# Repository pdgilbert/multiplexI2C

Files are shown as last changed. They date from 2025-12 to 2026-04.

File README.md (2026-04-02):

# multiplexI2C
Eight 4-position screw connectors on multiplexed on I2C with PCA9548A. 
This allows connecting 8 I2C sensors such as AHT10 (on module boards) using 
low voltage 4-wire cable.

##  Status: Working Prototype.

## Summary

Kicad project WIP.

PCB design to connect multiple (up to 8) I2C sensors (eg. AHT20) to a I2C multiplexer
connecting to an MCU. Sensor connectors are  4-pin KF128-2.54-4P generic screw terminals.
Many types of I2C sensors are inexpensive and easily available on module boards, 
but 4-wire cable will typically need to be attached. 

The pcb board has a LoRa radio on a SPI bus which transmits measurement results.
There is also a I2C header for an optional OLED display, intended mainly for debugging.

Related software is in repository https://github.com/pdgilbert/SensorProject_th8.

As of December 2025, this repository has three important branches. (Branch `main` is not 
an important branch but rather a somewhat stable version of the most active
development, which is on the `dev` branch. Both may be removed or reorganized 
in the future.)
 
Branch `blackpill-socket` has two 20-pin sockets arranged for a commonly available 
blackpill module. It has an RFM95 LoRa radio on spi, an I2C pinsocket arrange to plug in 
an SSD module for display, and 8 4-pin terminals multiplexed to connect I2C devices.
The pinsocket arrangement can also be used for jumper-wiring MCUs on other development
boards. Further work on this branch will be limited.
 
Branch `f411-RFM95W-module` has a footprint for a module with an MCU and LoRa radio.
(See repository MCU-LoRa for module details.)
It has a socket for I2C arranged to plug in an SSD module for display, 
and 8 4-pin terminals multiplexed to connect I2C devices. 
As of November 2025 this branch is almost ready to manufacture a prototype.
 
Branch `f411-RFM95W` has an STM32F411 MCU and RFM95W LoRa radio on the board (no module).
It has a socket for I2C arrange to plug in an SSD module for display, 
and 8 4-pin terminals multiplexed to connect I2C devices. 
As of December 2025 this branch is almost ready to manufacture a prototype.

See history further below for regarding status and testing of each branch.

Graphics below will be different on different branches, reflecting the differences above.
The `.png` files below are produced from kicad  in the `3D Viewer`  
with `File > Export Current View as PNG`.
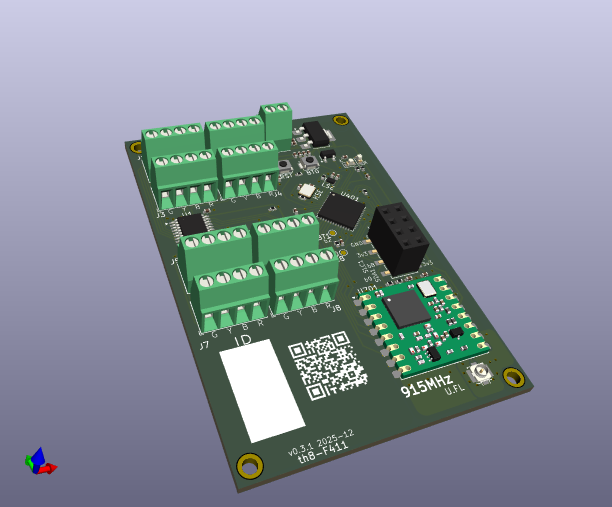
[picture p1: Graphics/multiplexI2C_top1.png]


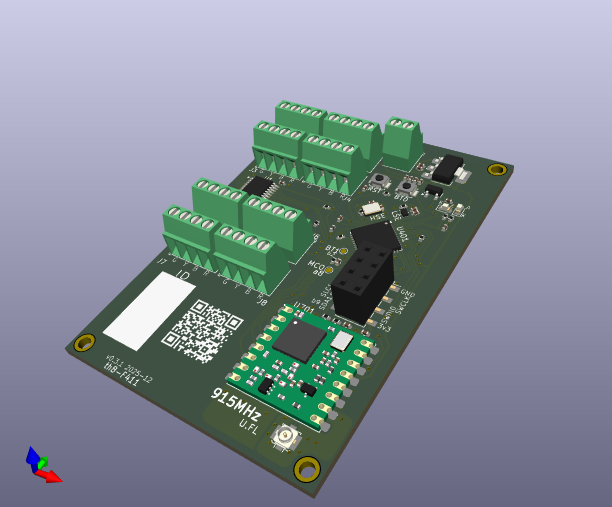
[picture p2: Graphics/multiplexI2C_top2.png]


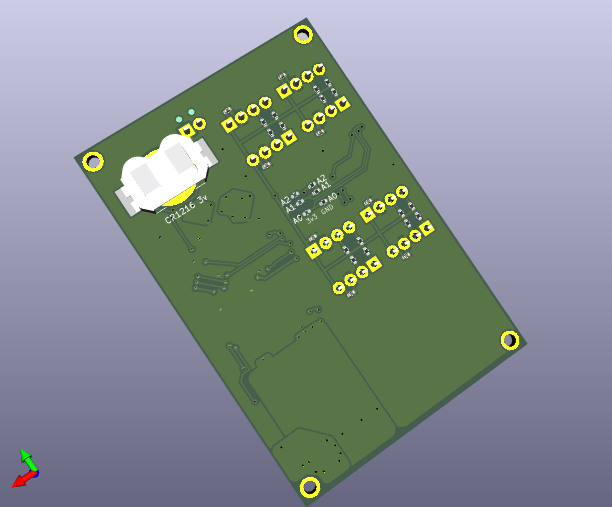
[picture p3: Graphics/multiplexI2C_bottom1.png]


( hints from https://docs.github.com/en/repositories/working-with-files/using-files/working-with-non-code-files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 )

3D  `.wrl` file opens with Meshlab. Good, full colour. 
The file needs to be load into a viewer (e.g.
https://3dviewer.net/#model=https://github.com/pdgilbert/multiplexI2C/f411-RFM95W/Graphics/multiplexI2C.wrl )
or downloaded and viewed with your own viewer. 
To download go to the file in the Graphics/ directory and click on the file.
Github will try to render this, but fails because it is too large.
Then click on the download raw file icon at the top right. 
The file is produced from kicad  with `File > Export ... >  VRML...`
.wrl file
https://3dviewer.net/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

3D  `.step` file can be loaded by Freecad. 
It can be load into a viewer (e.g. 
https://3dviewer.net/#model=https://github.com/pdgilbert/multiplexI2C/f411-RFM95W/Graphics/multiplexI2C.step)
or downloaded as above for `.wrl`.
The file is produced from kicad  with `File > Export ... >  STEP...`
.step file

3D  `.stl` file can be  rendered by Github, Meshlab and Freecad. So far only mono-colour is working. 
It can be load into a viewer (e.g. 
https://3dviewer.net/#model=https://github.com/pdgilbert/multiplexI2C/f411-RFM95W/Graphics/multiplexI2C.stl)
To render by Meshlab or Freecad requires downloading as above for `.wrl`.
The file is best produced by exporting a `.wrl` or `.step` file from kicad and
importing that to Meshlab or Freecad, and then exporting an `.stl` file.
The file can also be produced from kicad  with `File > Export ... >  STEP.../STEP...` but
the result has bad artifacts. The .wrl version is much better than the .stl version.
.stl file

3D  `.ast` file (ASCII stl) is rendered by Github, according to above link, but files  
larger than 10 MB are too big for GitHub to display. 
The `multiplexI2C.ast` is almost 20MB so this format cannot be used by Github.
It is not rendered by Meshlab.
.ast file

## History
 
 - `th8-F411` version `0.3.1 2025-12` (branch `f411-RFM95W`) has stm32f411 MCU chip and HopeRF RFM95W.
    This version is switched to ssd on I2C1 and sensors on I2C2, so it is consistent with SensorProject_t16.
    The software has a flag to indicate previous old versions.

 - `th8-F411` version `0.3.1M 2025-12` (branch `f411-RFM95W-module`) has not been manufactured/tested.

 - Version `0.1.1 2025-01` (branch `blackpill-socket`) has pull up resistor added but 
   has not been manufactured/tested. This version has ssd on I2C2 and sensors on I2C1.

 - Version `0.1.0 2024-09` (branch `blackpill-socket`) needs manual addition of a pull up 
   resistor to nss of the RFM95W radio module, MCU pin A4. 
   With this modification it works with `blackpill` `stm32f401` or `stm32f411` inserted,
   using AHT10 and AHT20 sensors. With jumper wiring it has also been used to test a WeAct 
   Studio STM32474G474 board.  This version has ssd on I2C2 and sensors on I2C1.
   See notes re testing in the software repository.

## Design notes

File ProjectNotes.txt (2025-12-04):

grep "/////////////// " ProjectNotes.txt   # for section index

////////////////////////////////////////////////////////////////////////////////
///////////////     General Notes
////////////////////////////////////////////////////////////////////////////////

(See also file `README.md`.)

The 8   4-wire screw down connectors provide gnd, 3.3v, and multiplex I2c (SCL and SDA). 

The PCB board is 48.26mm by 71.12mm, which fits (tightly) in a standard NA electric outlet hole. 
This allows for a standard outlet faceplate cover. The board needs to be supplied by low voltage (5v).
An outlet box is not a good option because of the number of sensor wires, but a low voltage single gang 
wall plate with no back, as often used for audio or TV cable, is a good option.

The mounting hole centers are 43.5mm apart in x direction and 66.4 mm in y direction.
On versions with the MCU-LoRa module one mounting hole is moved from the corner. 
It is 20.10mm  in the x direction from the adjacent hole.

In addition to the 8 multiplex I2c connectors and the LoRa module, the board has 
  - 4 pins on an 8 pin header to connect a ST-link programming dongle.
  - 4 pins on an 8 pin header to connect ssd display on I2C1.
  - a red led indicating when it is powered up.
  - a blue led on pin PC13 which can be programmed to turn on and off.
  - a 25 MHz crystal for the high speed external (HSE) oscillator. (still untested)
  - a 32.768 kHz crystal for the low speed external (LSE) oscillator. (still untested)
  - a coin cell battery holder to supply the real time clock (RTC). (still untested)
  
The HSE, LSE, and RTC are not used by current software but are on the board for future possibilities.

- AHT10 sensor module reference  https://www.electroschematics.com/temperature-sensor/

////////////////////////////////////////////////////////////////////////////////
///////////////            To Do
////////////////////////////////////////////////////////////////////////////////

- consider screwless terminal connector, eg KEFA  KF141V_4P 
  or  KF208VB-2.5/2.54  Spring type terminal block,
  (https://www.kefaelectronic.com/KF208VB-2-5-2-54-Spring-type-terminal-block-pd563040758.html)
  or Würth Elektronik	 691403900004B
  or https://abra-electronics.com/interconnects/terminals-blocks-barrier/spring-terminals/2427p-screwless-terminal-block-4-pin-0.1-pitch-top-entry-2-pack.html
  or  WAGO 2086-1104-700-000_997-605 but a bit smaller would be better,
  and SMT would be nice. Consider possibly multileveel 45 degree?
  or https://www.kefaelectronic.com/KFM736H4-Spring-type-terminal-block-pd555948668.html
     https://www.lcsc.com/category/432.html
     https://www.lcsc.com/product-detail/C2974939.html

-spice

////////////////////////////////////////////////////////////////////////////////
///////////////     BOM / Parts / reference
////////////////////////////////////////////////////////////////////////////////
     
========fabrication files ==========

Necessary files  https://www.pcbway.com/smt_ordering_guide.html

Generate BOM_auto.csv  and edit to BOM.csv

Generate 11 .grb files in ./outputs  

Generate  2 .drl files in ./outputs

[indicates  hole counts   plated pads: 127  non-plated:2  through vias:16  micro vias: 0  buried vias:0 ]

Generate centroid position file   > Fabrication Ouputs  > Component Placement (.csv not .pos)
[indicates componet count 56 ]
check  J**1 and J**2 and DNP R0 are removed or edit them from the file.

then  zip multiplexI2C-gerbers.zip  *.gbr *.drl

======= submit and get Quote ========

Following  (The First Way)
  https://www.pcbway.com/helpcenter/pcb_assembly_ordering/How_to_Upload_PCB_Assembly_PCBA__Inquiry.html 

Quote assembly  and PCB  https://www.pcbway.com/pcb-assembly.html (sign in)
         Assembly
            quantity     5
            unique parts  13
            SMT         parts : 37   Pads:  110
            BGA QFP     parts : 1
            Thru-Holes  parts : 14   Pads:   82 (plus 4 mounting holes)
         PCB
            length      70.9 mm
            width       48   mm
            num (pcs)    5
            layers       2
            thickness    1.6 mm

material FR-4   S1000H TG150
min track spacing?  left at 6/6mil

Step 2 + Additional Options:
-Do not add paste for 40 through hole pads (2 rows of 20) marked 
SolderWire-0.25sqmm_1x20 on the F.Fab layer. These pads are
not used.

Step 3 + Additional Options:   png NOT VALID FORMAT so not submitted
-3D render of front and back are included as png files. The spring antenna displays as a box in the rendering.
    
===============================

///////////////     Version Notes  See README.md

////////////////////////////////////////////////////////////////////////////////
///////////////     Notes on LoRa
////////////////////////////////////////////////////////////////////////////////

- LoRa module RFM95W-915S2 (RFM95W module at 915MHz band, SMD Package) based
on Semtech sx1276 chipset and used radio-sx127x rust crate.

https://www.instructables.com/Introduction-LoRa-Module-RFM95-RFM95W-Hoperf/
https://cdn.sparkfun.com/assets/learn_tutorials/8/0/4/RFM95_96_97_98W.pdf
https://stackoverflow.com/questions/35780290/how-can-i-use-hardware-nss-spi-on-stm32f4

Sometime probably move to G-NiceRF LoRa-CC68-915 or Cdebyte E220-900M22S (branch e220) 
using RF Semtech chipset llcc68, but first need rust crate for radio/module.
  https://www.nicerf.com/lora-module/3438.html  Download datasheet and demo code from our website.
  
 Note  E220-900MM22S is not the same as E220-900M22S
 https://www.cdebyte.com/products/E220-900T22D/7#Series
 https://device.report/manual/2458480

////////////////////////////////////////////////////////////////////////////////
///////////////     Notes on PCA/TCA9548 pullup resistors
////////////////////////////////////////////////////////////////////////////////

See  http://www.ti.com/lit/pdf/SLVA689 re pullup sensor size.  !! very good

and  www.ti.com   ADS1113, ADS1114, ADS1115
SBAS444E 2013 MAY 2009 2013 REVISED DECEMBER 2024
p28
"Long bus lines have higher
capacitance and require smaller pullup resistors to compensate. Do not use resistors that are too small to avoid
bus drivers being unable to pull the bus lines low."

pullup 10k vs 20k? vs 4.7k?  Consider pullup on sensor so small resister can be used with long wires and
power is not lost when there is no sensor.

4.7k seems to be needed sometimes on short wires, while 10k sometimes works on long wires.
Possibly poor connections on RJ11 or on AHT10 module boards.
Should use 4.7k to help insure better signal. Additional power should be small.
In case of still bad signal: additional resistors can be added can be added in the J1 .. J8 connectors
from power to SC and to SD, beside wires to the sensor module.

With prototype v1.0.0 2024-09 
   AHT10 on 6m POT 22AWG does not work (4m does work)
            6m does work with Tupavco TP801 "rounded phone cable" which is about 26 AWG

////////////////////////////////////////////////////////////////////////////////
///////////////     Notes on TCA9548 address 
////////////////////////////////////////////////////////////////////////////////
datasheet
https://www.ti.com/document-viewer/TCA9548A/datasheet#device-address-scps2079628/SCPS2079628

Fixed address:

- The default only address could be specified by wiring A0, A1, A2 to GND.

- Other address could be specifed with GND and VCC wired settings.

Changeable address:

- Final decision to use R0 pads as described below. 

- a jumper block is possible but error prone. The jumper has to go to either GND or VCC, which is 
possibly error prone. (A missing jumper would cause floating.)

- Solder pads for 0 ohm resistors (or, possibly less reliable, solder bridges) can be setup to 
change GND and VCC settings. This requires a solder iron and is not easily changed "in the field". 
Not does not seem likely that changing in the fiel is needed since that would require a software
change flashed to the MCU. And an accidental change would break things.

- A DIP style switch can be used. The need for either GND or VCC means a pull-up or pull-down resistor
is needed for each address pin A:

 The usual. Switch X open pulls A high through R to VCC. X closed pulls A low to GND. 
              A    --- R --- VCC
                    |
                    X ---- GND

 The alternate. Switch X open pulls A low through R to GND. X closed pulls A high to VCC.
                  A   --- X ---  VCC
                       |
                       --- R --- GND

 In either case one address setting causes a power loss from Vcc through R to ground.
 With VCC=3.2v and R = 100 K ohms The current is 0.032 mA and the power loss 0.01 mW per address.
 According to the datasheet section 6.5 the current flow through A is max 0.001 mA when there is a direct 
 connection to GND or VCC. 
 This flow is even in the case the MCU and  PCA9548 are in sleep mode. 
 That is not attractive for battery or solar opperation so the resistor R should be as large
 as possible but still achieve necesssary high/low voltage. 
 
 From the datasheet section 6.3 high should be at least 0.7 x Vcc and low should be less than 0.3 x Vcc.
 So with Vcc 3.2v  high is at least 2.24v and low is less than 0.96v.
 The necessary check in the alternate configuration is that with X open the drop from A to GND is 
 less than 0.96v. At max current 0.001 mA the voltage drop through a 100 K ohm resistor is 0.1v.
 Thus an even large resistance would be possible.

 The alternate configuration is used so there is no power loss through R in the most usual 
 setting  -  all address 0. X open and A pulled low to ground through R. In less usual situations where 
 some address pins are high the power supply will likely need to be more robust for other reasons too.

////////////////////////////////////////////////////////////////////////////////

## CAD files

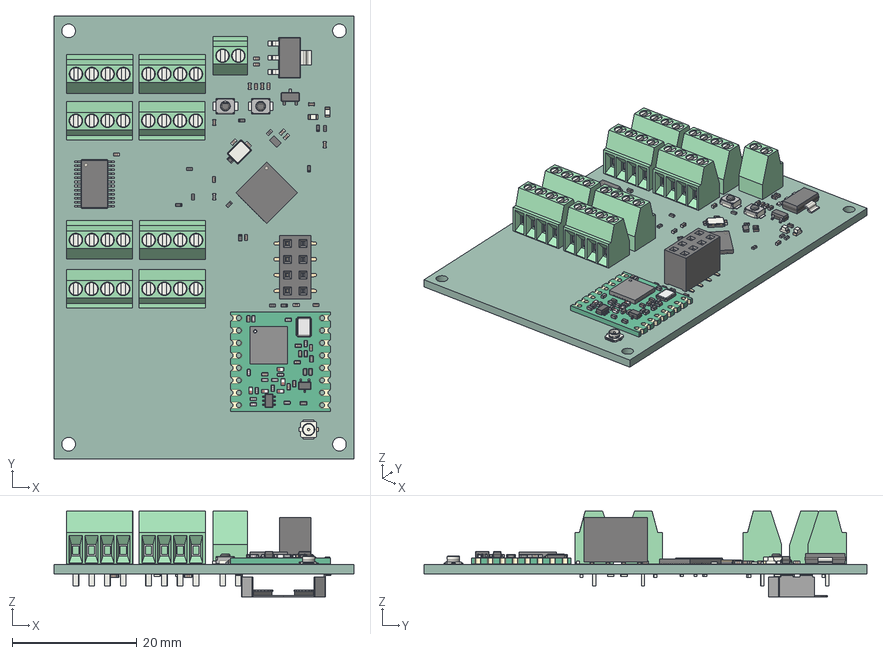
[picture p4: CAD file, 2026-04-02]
Graphics/multiplexI2C.step
48.2 x 71.1 x 13.8 mm
R_0402_1005Metric x 35
C_0402_1005Metric x 26
TerminalBlock_Phoenix_MPT-0,5-2-2.54_1x02_P2.54mm_Horizontal
QFN 28 v2
SMD Crystal v1
CAP 0403 v1 x 8
CAP Ceramic 0403 v1 x 8
Res 0403 v1 x 4
CAP ML 0403 v1 x 5
SOT-323 v1
Inductor SMD 0403 v1 x 5
SOT-363 v1
TerminalBlock_Phoenix_MPT-0,5-4-2.54_1x04_P2.54mm_Horizontal x 8
LED_0603_1608Metric x 2
Crystal_SMD_SeikoEpson_FA238-4Pin_3.2x2.5mm
L_0402_1005Metric
U.FL_Hirose_U.FL-R-SMT-1_Vertical
Crystal_SMD_MicroCrystal_CM9V-T1A-2Pin_1.6x1.0mm
QFN-48-1EP_7x7mm_P0.5mm_EP5.15x5.15mm
TSSOP-24_4.4x7.8mm_P0.65mm
PinSocket_2x04_P2.54mm_Vertical_SMD
SOT-223
SOT-23
SW_SPST_B3U-1000P x 2
BatteryHolder_LINX_BAT-HLD-012-SMT
multiplexI2C_PCB

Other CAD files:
Graphics/multiplexI2C.stl

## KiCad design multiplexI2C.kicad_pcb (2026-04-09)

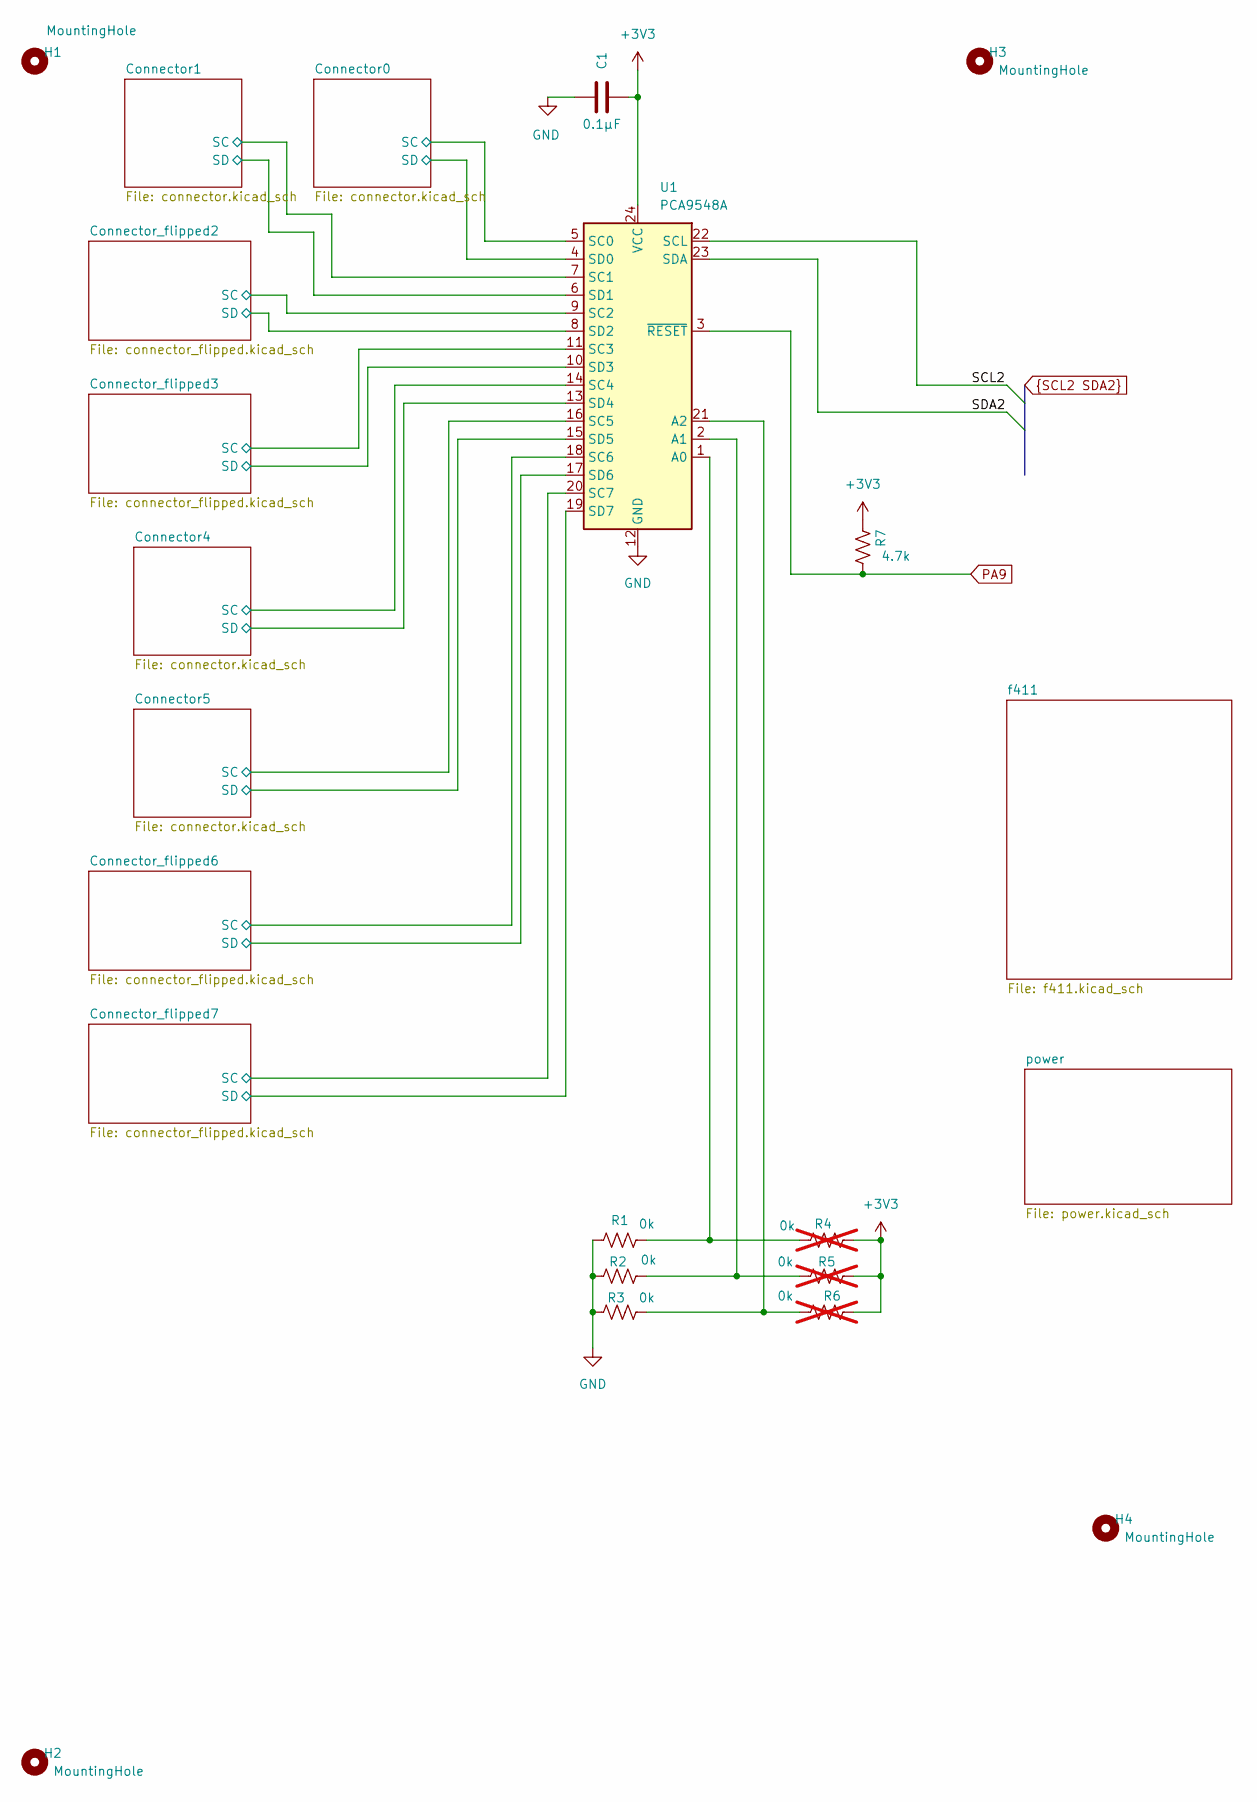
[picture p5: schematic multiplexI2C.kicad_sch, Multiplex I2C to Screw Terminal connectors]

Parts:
C1: 0.1µF; C_0402_1005Metric
H1, H2, H3, H4: MountingHole; MountingHole_2.2mm_M2_ISO7380_Pad
R1, R2, R3: 0k; R_0402_1005Metric
R4, R5, R6: 0k; R_0402_1005Metric; not fitted
R7: 4.7k; R_0402_1005Metric
U1: PCA9548A; TSSOP-24_4.4x7.8mm_P0.65mm; MfgPart PCA9548APW

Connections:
+3V3: C1.1, R4.1, R5.1, R6.1, R7.1, U1.24 (VCC); also elsewhere on the board
/Connector0/SC: U1.5 (SC0); also elsewhere on the board
/Connector0/SD: U1.4 (SD0); also elsewhere on the board
/Connector1/SC: U1.7 (SC1); also elsewhere on the board
/Connector1/SD: U1.6 (SD1); also elsewhere on the board
/Connector4/SC: U1.14 (SC4); also elsewhere on the board
/Connector4/SD: U1.13 (SD4); also elsewhere on the board
/Connector5/SC: U1.16 (SC5); also elsewhere on the board
/Connector5/SD: U1.15 (SD5); also elsewhere on the board
/Connector_flipped2/SC: U1.9 (SC2); also elsewhere on the board
/Connector_flipped2/SD: U1.8 (SD2); also elsewhere on the board
/Connector_flipped3/SC: U1.11 (SC3); also elsewhere on the board
/Connector_flipped3/SD: U1.10 (SD3); also elsewhere on the board
/Connector_flipped6/SC: U1.18 (SC6); also elsewhere on the board
/Connector_flipped6/SD: U1.17 (SD6); also elsewhere on the board
/Connector_flipped7/SC: U1.20 (SC7); also elsewhere on the board
/Connector_flipped7/SD: U1.19 (SD7); also elsewhere on the board
GND: C1.2, R1.2, R2.2, R3.2, U1.12 (GND); also elsewhere on the board
unnamed: R1.1, R4.2, U1.1 (A0)
unnamed: R2.1, R5.2, U1.2 (A1)
unnamed: R3.1, R6.2, U1.21 (A2)
PA9: R7.2, U1.3 (~RESET); also elsewhere on the board
SCL2: U1.22 (SCL); also elsewhere on the board
SDA2: U1.23 (SDA); also elsewhere on the board

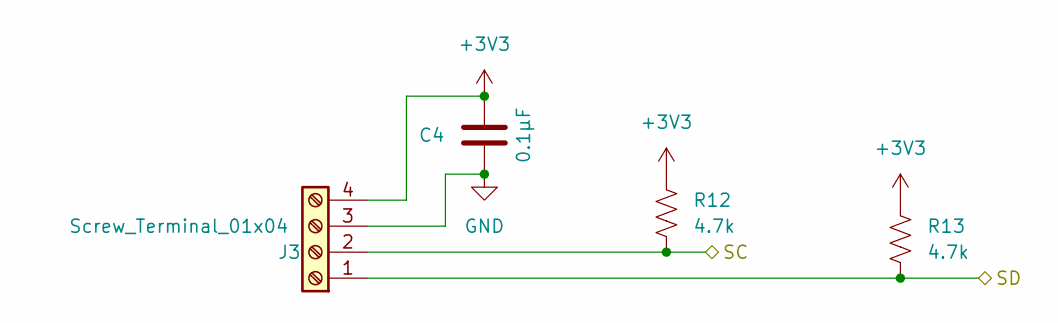
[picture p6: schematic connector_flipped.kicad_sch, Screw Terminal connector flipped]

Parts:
C4: 0.1µF; C_0402_1005Metric
J3: Screw_Terminal_01x04; TerminalBlock_Phoenix_MPT-0,5-4-2.54_1x04_P2.54mm_Horizontal; MfgPart KF128-2.54-4P
R12, R13: 4.7k; R_0402_1005Metric

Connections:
+3V3: C4.1, J3.4, R12.1, R13.1; also elsewhere on the board
/Connector_flipped2/SC: J3.2, R12.2; also elsewhere on the board
/Connector_flipped2/SD: J3.1, R13.2; also elsewhere on the board
GND: C4.2, J3.3; also elsewhere on the board

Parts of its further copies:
C5, C8, C9: 0.1µF; C_0402_1005Metric
J4, J7, J8: Screw_Terminal_01x04; TerminalBlock_Phoenix_MPT-0,5-4-2.54_1x04_P2.54mm_Horizontal; MfgPart KF128-2.54-4P
R14, R15, R20, R21, R22, R23: 4.7k; R_0402_1005Metric

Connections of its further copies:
+3V3: C5.1, C8.1, C9.1, J4.4, J7.4, J8.4, R14.1, R15.1, R20.1, R21.1, R22.1, R23.1; also elsewhere on the board
/Connector_flipped3/SC: J4.2, R14.2; also elsewhere on the board
/Connector_flipped3/SD: J4.1, R15.2; also elsewhere on the board
/Connector_flipped6/SC: J7.2, R20.2; also elsewhere on the board
/Connector_flipped6/SD: J7.1, R21.2; also elsewhere on the board
/Connector_flipped7/SC: J8.2, R22.2; also elsewhere on the board
/Connector_flipped7/SD: J8.1, R23.2; also elsewhere on the board
GND: C5.2, C8.2, C9.2, J4.3, J7.3, J8.3; also elsewhere on the board

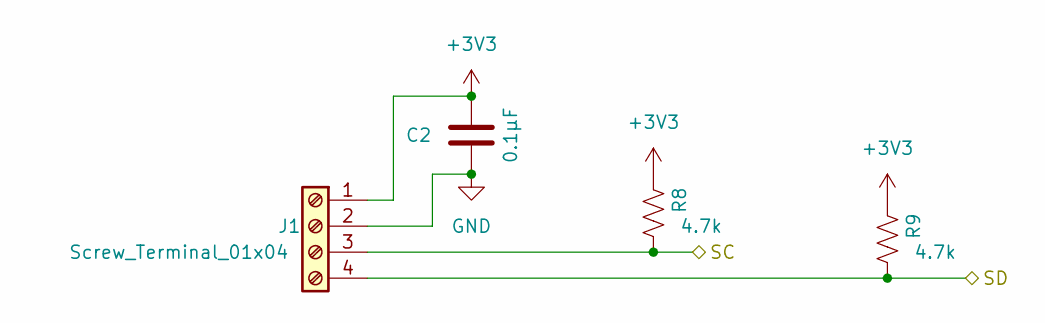
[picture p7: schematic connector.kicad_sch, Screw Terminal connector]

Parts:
C2: 0.1µF; C_0402_1005Metric
J1: Screw_Terminal_01x04; TerminalBlock_Phoenix_MPT-0,5-4-2.54_1x04_P2.54mm_Horizontal; MfgPart KF128-2.54-4P
R8, R9: 4.7k; R_0402_1005Metric

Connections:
+3V3: C2.1, J1.1, R8.1, R9.1; also elsewhere on the board
/Connector0/SC: J1.3, R8.2; also elsewhere on the board
/Connector0/SD: J1.4, R9.2; also elsewhere on the board
GND: C2.2, J1.2; also elsewhere on the board

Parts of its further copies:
C3, C6, C7: 0.1µF; C_0402_1005Metric
J2, J5, J6: Screw_Terminal_01x04; TerminalBlock_Phoenix_MPT-0,5-4-2.54_1x04_P2.54mm_Horizontal; MfgPart KF128-2.54-4P
R10, R11, R16, R17, R18, R19: 4.7k; R_0402_1005Metric

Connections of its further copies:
+3V3: C3.1, C6.1, C7.1, J2.1, J5.1, J6.1, R10.1, R11.1, R16.1, R17.1, R18.1, R19.1; also elsewhere on the board
/Connector1/SC: J2.3, R10.2; also elsewhere on the board
/Connector1/SD: J2.4, R11.2; also elsewhere on the board
/Connector4/SC: J5.3, R16.2; also elsewhere on the board
/Connector4/SD: J5.4, R17.2; also elsewhere on the board
/Connector5/SC: J6.3, R18.2; also elsewhere on the board
/Connector5/SD: J6.4, R19.2; also elsewhere on the board
GND: C3.2, C6.2, C7.2, J2.2, J5.2, J6.2; also elsewhere on the board

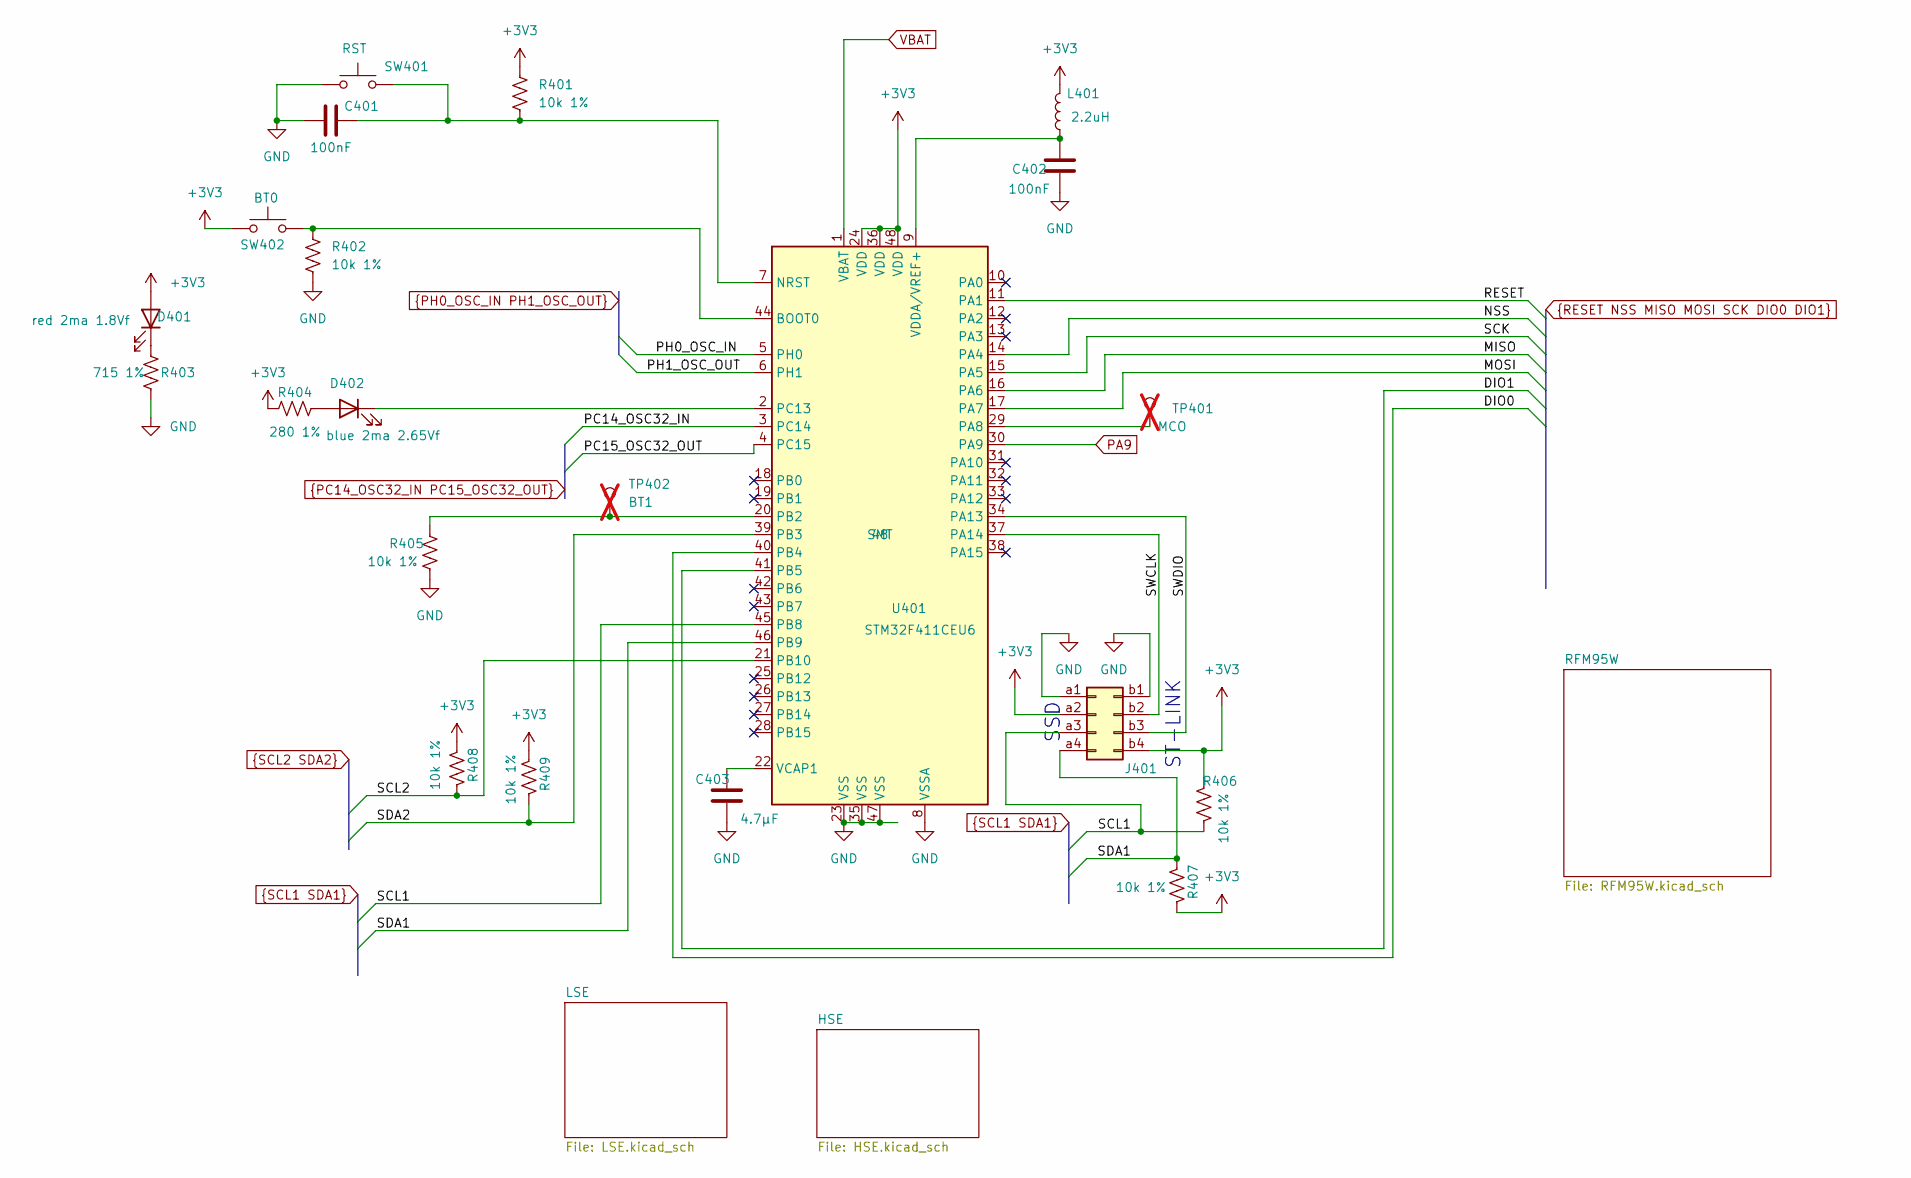
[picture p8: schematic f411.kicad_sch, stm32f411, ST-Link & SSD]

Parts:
C401, C402: 100nF; C_0402_1005Metric
C403: 4.7µF; C_0402_1005Metric
D401: red 2ma 1.8Vf; LED_0603_1608Metric; MfgPart APT1608LSECK/J3-PRV
D402: blue 2ma 2.65Vf; LED_0603_1608Metric; MfgPart APT1608LVBC/D
J401: Conn_02x04_Top_Bottom; PinSocket_2x04_P2.54mm_Vertical_SMD; MfgPart HC-PM254-5.0H-2x4PS-02A
L401: 2.2uH; L_0402_1005Metric; MfgPart MLZ1005M2R2WT000
R401, R402, R405, R406, R407, R408, R409: 10k 1%; R_0402_1005Metric
R403: 715 1%; R_0402_1005Metric
R404: 280 1%; R_0402_1005Metric
SW401, SW402: SW_Push; SW_SPST_B3U-1000P; MfgPart B3U-1000P
TP401: MCO; TestPoint_Pad_D1.0mm; not fitted
TP402: BT1; TestPoint_Pad_D1.0mm; not fitted
U401: STM32F411CEU6; QFN-48-1EP_7x7mm_P0.5mm_EP5.6x5.6mm; MfgPart STM32F411CEU6

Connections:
+3V3: D401.2 (A), J401.a2, J401.b4, L401.2, R401.1, R404.1, R406.1, R407.2, R408.1, R409.1, SW402.1, U401.24 (VDD), U401.36 (VDD), U401.48 (VDD); also elsewhere on the board
/f411/SWCLK: J401.b2, U401.37 (PA14)
/f411/SWDIO: J401.b3, U401.34 (PA13)
DIO0: U401.40 (PB4); also elsewhere on the board
DIO1: U401.41 (PB5); also elsewhere on the board
GND: C401.1, C402.2, C403.2, J401.a1, J401.b1, R402.2, R403.2, R405.2, SW401.1, U401.8 (VSSA), U401.23 (VSS), U401.35 (VSS), U401.47 (VSS), U401.49 (VSS); also elsewhere on the board
MISO: U401.16 (PA6); also elsewhere on the board
MOSI: U401.17 (PA7); also elsewhere on the board
NSS: U401.14 (PA4); also elsewhere on the board
unnamed: D401.1 (K), R403.1
unnamed: D402.2 (A), R404.2
unnamed: D402.1 (K), U401.2 (PC13)
unnamed: R402.1, SW402.2, U401.44 (BOOT0)
unnamed: C401.2, R401.2, SW401.2, U401.7 (NRST)
unnamed: TP401.1, U401.29 (PA8)
unnamed: R405.1, TP402.1, U401.20 (PB2)
unnamed: C403.1, U401.22 (VCAP1)
unnamed: C402.1, L401.1, U401.9 (VDDA/VREF+)
PA9: U401.30 (PA9); also elsewhere on the board
PC14_OSC32_IN: U401.3 (PC14); also elsewhere on the board
PC15_OSC32_OUT: U401.4 (PC15); also elsewhere on the board
PH0_OSC_IN: U401.5 (PH0); also elsewhere on the board
PH1_OSC_OUT: U401.6 (PH1); also elsewhere on the board
RESET: U401.11 (PA1); also elsewhere on the board
SCK: U401.15 (PA5); also elsewhere on the board
SCL1: J401.a3, R406.2, U401.45 (PB8)
SCL2: R408.2, U401.21 (PB10); also elsewhere on the board
SDA1: J401.a4, R407.1, U401.46 (PB9)
SDA2: R409.2, U401.39 (PB3); also elsewhere on the board
VBAT: U401.1 (VBAT); also elsewhere on the board

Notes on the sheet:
SSD
ST-LINK

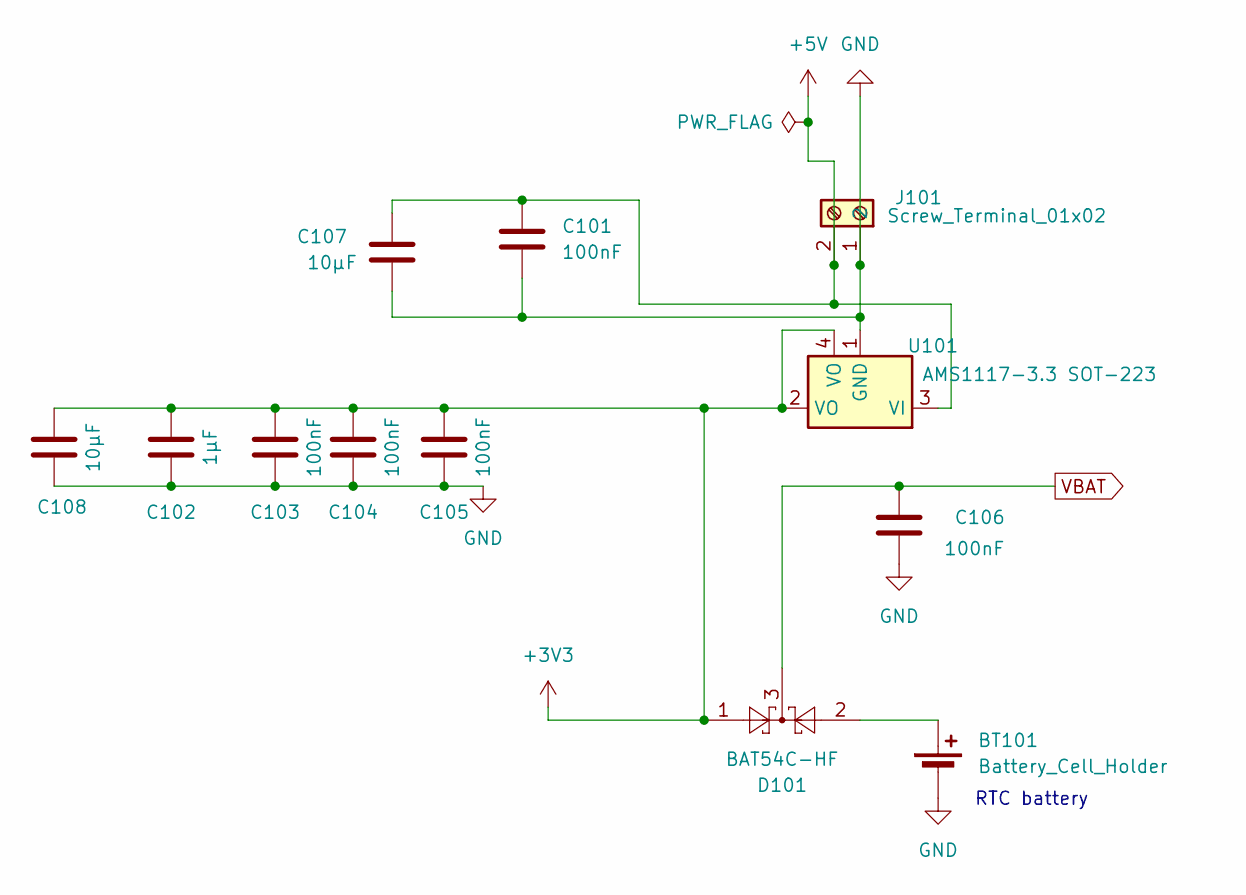
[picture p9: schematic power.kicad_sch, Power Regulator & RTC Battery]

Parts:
BT101: Battery_Cell_Holder; BatteryHolder_LINX_BAT-HLD-012-SMT; MfgPart BAT-HLD-012-SMT
C101, C103, C104, C105, C106: 100nF; C_0402_1005Metric
C102: 1µF; C_0402_1005Metric
C107, C108: 10µF; C_0402_1005Metric
D101: BAT54C-HF; SOT-23; MfgPart BAT54C-HF
J101: Screw_Terminal_01x02; TerminalBlock_Phoenix_MPT-0,5-2-2.54_1x02_P2.54mm_Horizontal; MfgPart KF128-2.54-2P
U101: AMS1117-3.3 SOT-223; SOT-223; MfgPart AMS1117-3.3

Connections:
+3V3: C102.1, C103.1, C104.1, C105.1, C108.1, D101.1, U101.2 (VO), U101.4 (VO); also elsewhere on the board
+5V: C101.1, C107.1, J101.2, U101.3 (VI)
GND: BT101.2 (-), C101.2, C102.2, C103.2, C104.2, C105.2, C106.2, C107.2, C108.2, J101.1, U101.1 (GND); also elsewhere on the board
unnamed: BT101.1 (+), D101.2
VBAT: C106.1, D101.3; also elsewhere on the board

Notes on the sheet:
RTC battery

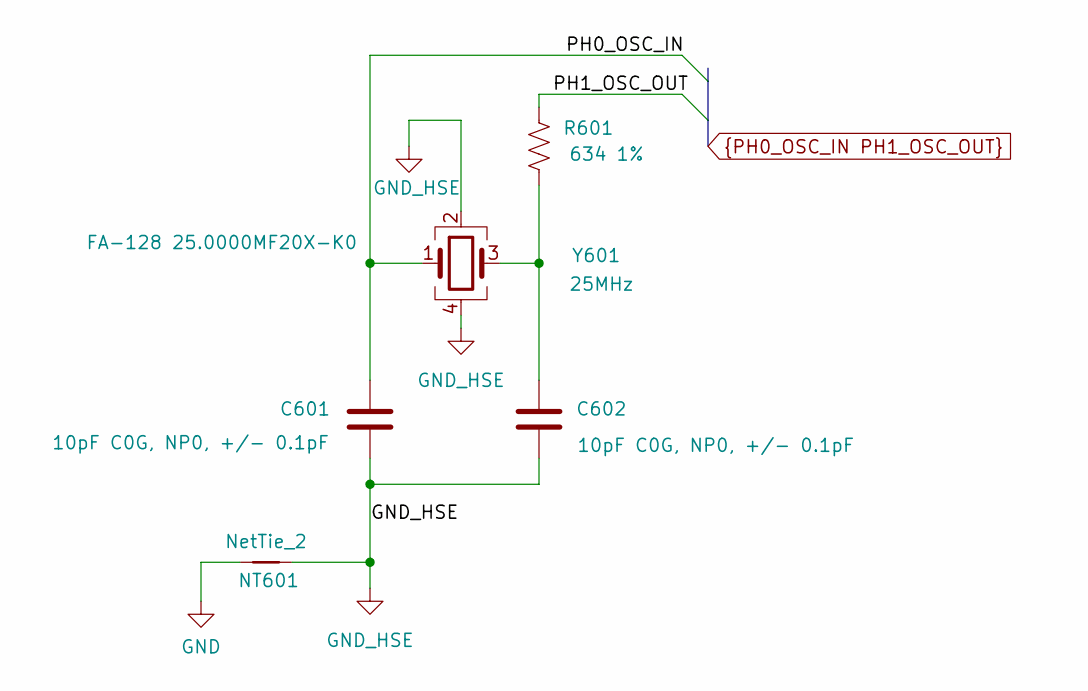
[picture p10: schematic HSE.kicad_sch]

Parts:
C601, C602: 10pF C0G, NP0, +/- 0.1pF; C_0402_1005Metric
NT601: NetTie_2; NetTie-2_SMD_Pad0.5mm
R601: 634 1%; R_0402_1005Metric
Y601: 25MHz; Crystal_SMD_2016-4Pin_2.0x1.6mm; MfgPart FA-128 25.0000MF20X-K0

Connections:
GND: NT601.1; also elsewhere on the board
GND_HSE: C601.1, C602.1, NT601.2, Y601.2, Y601.4
unnamed: C602.2, R601.2, Y601.3
PH0_OSC_IN: C601.2, Y601.1; also elsewhere on the board
PH1_OSC_OUT: R601.1; also elsewhere on the board

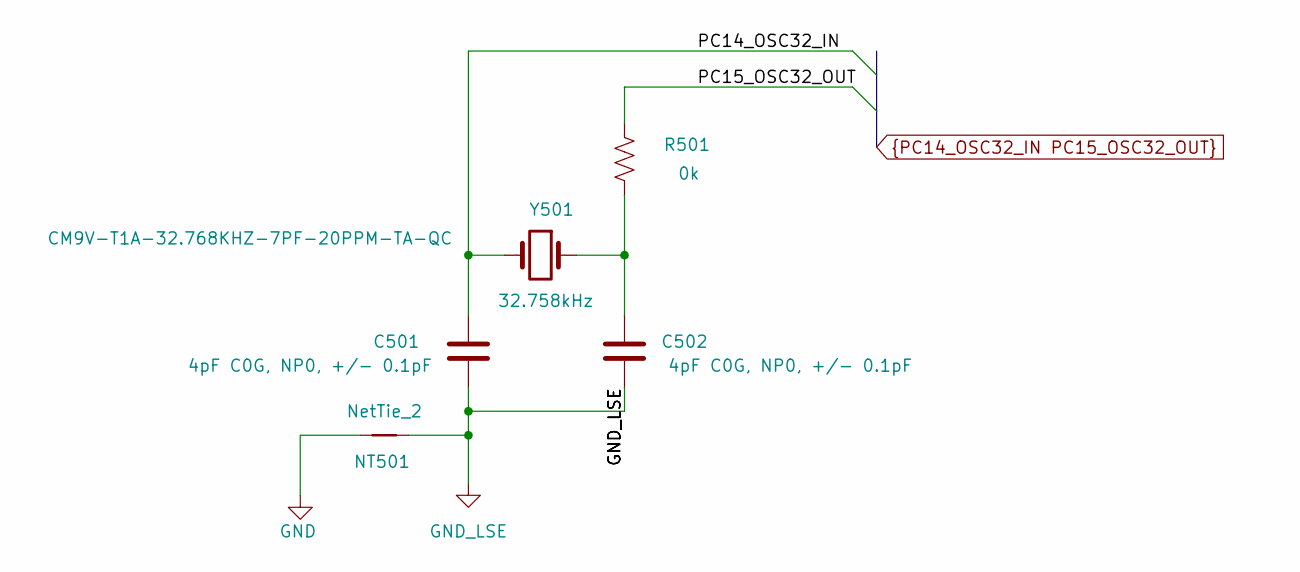
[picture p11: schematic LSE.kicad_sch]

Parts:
C501, C502: 4pF C0G, NP0, +/- 0.1pF; C_0402_1005Metric
NT501: NetTie_2; NetTie-2_SMD_Pad0.5mm
R501: 0k; R_0402_1005Metric
Y501: 32.758kHz; Crystal_SMD_MicroCrystal_CM9V-T1A-2Pin_1.6x1.0mm; MfgPart CM9V-T1A-32.768KHZ-7PF-20PPM-TA-QC

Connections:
GND: NT501.1; also elsewhere on the board
GND_LSE: C501.1, C502.1, NT501.2
unnamed: C502.2, R501.2, Y501.1
PC14_OSC32_IN: C501.2, Y501.2; also elsewhere on the board
PC15_OSC32_OUT: R501.1; also elsewhere on the board

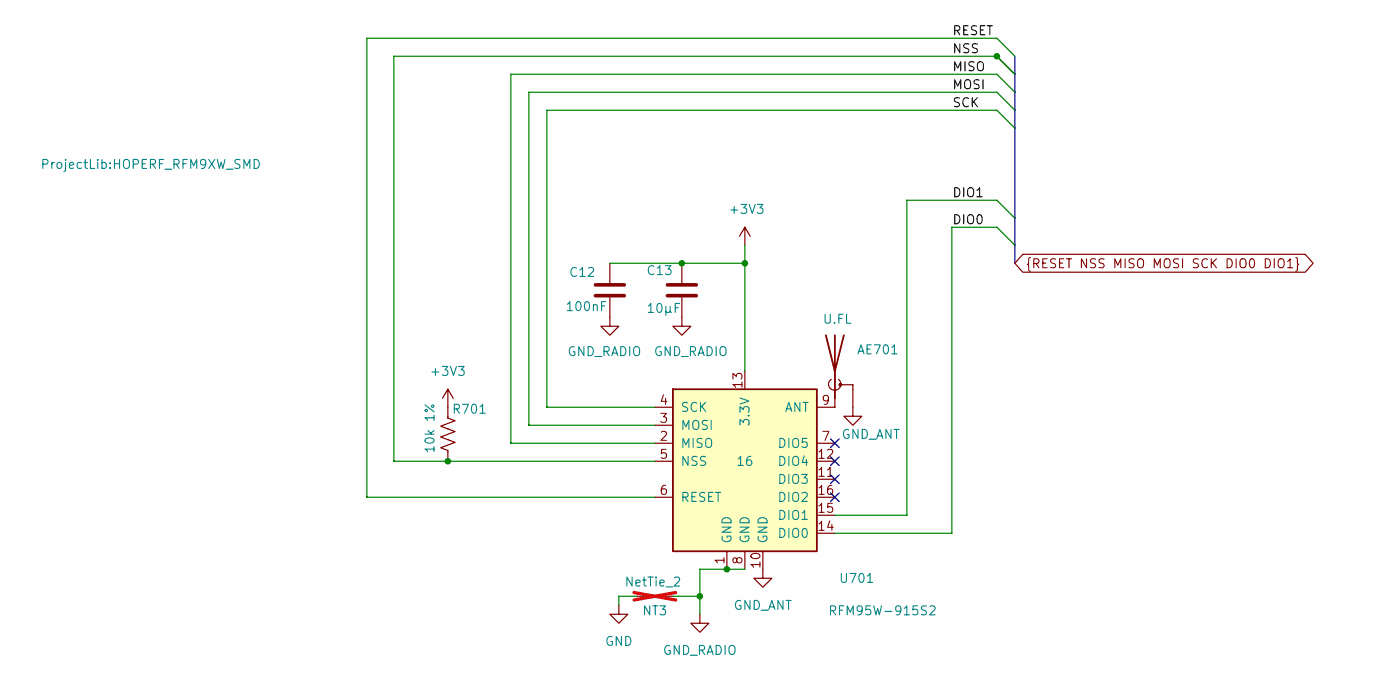
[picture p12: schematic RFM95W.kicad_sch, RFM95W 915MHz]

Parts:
AE701: U.FL; U.FL_Molex_MCRF_73412-0110_Vertical; MfgPart U.FL-R-SMT-K(800)
C12: 100nF; C_0402_1005Metric
C13: 10µF; C_0402_1005Metric
NT3: NetTie_2; NetTie-2_SMD_Pad0.5mm; not fitted
R701: 10k 1%; R_0402_1005Metric
U701: RFM95W-915S2; HOPERF_RFM9XW_SMD; MfgPart RFM95W-915S2

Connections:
+3V3: C12.1, C13.1, R701.1, U701.13 (3.3V); also elsewhere on the board
DIO0: U701.14 (DIO0); also elsewhere on the board
DIO1: U701.15 (DIO1); also elsewhere on the board
GND: NT3.1; also elsewhere on the board
GND_ANT: AE701.2 (Shield), U701.10 (GND)
GND_RADIO: C12.2, C13.2, NT3.2, U701.1 (GND), U701.8 (GND)
MISO: U701.2 (MISO); also elsewhere on the board
MOSI: U701.3 (MOSI); also elsewhere on the board
NSS: R701.2, U701.5 (NSS); also elsewhere on the board
unnamed: AE701.1 (A), U701.9 (ANT)
RESET: U701.6 (RESET); also elsewhere on the board
SCK: U701.4 (SCK); also elsewhere on the board

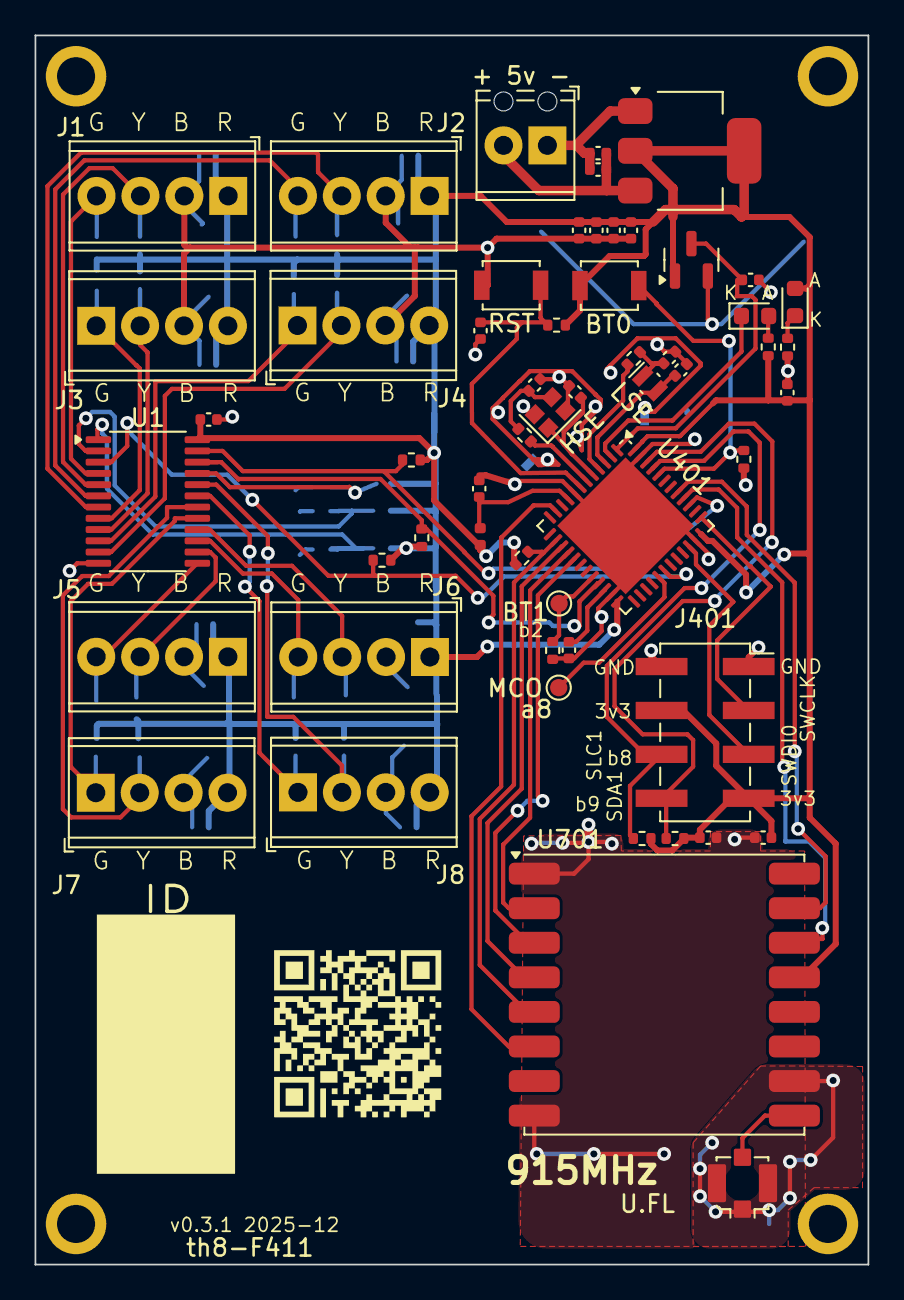
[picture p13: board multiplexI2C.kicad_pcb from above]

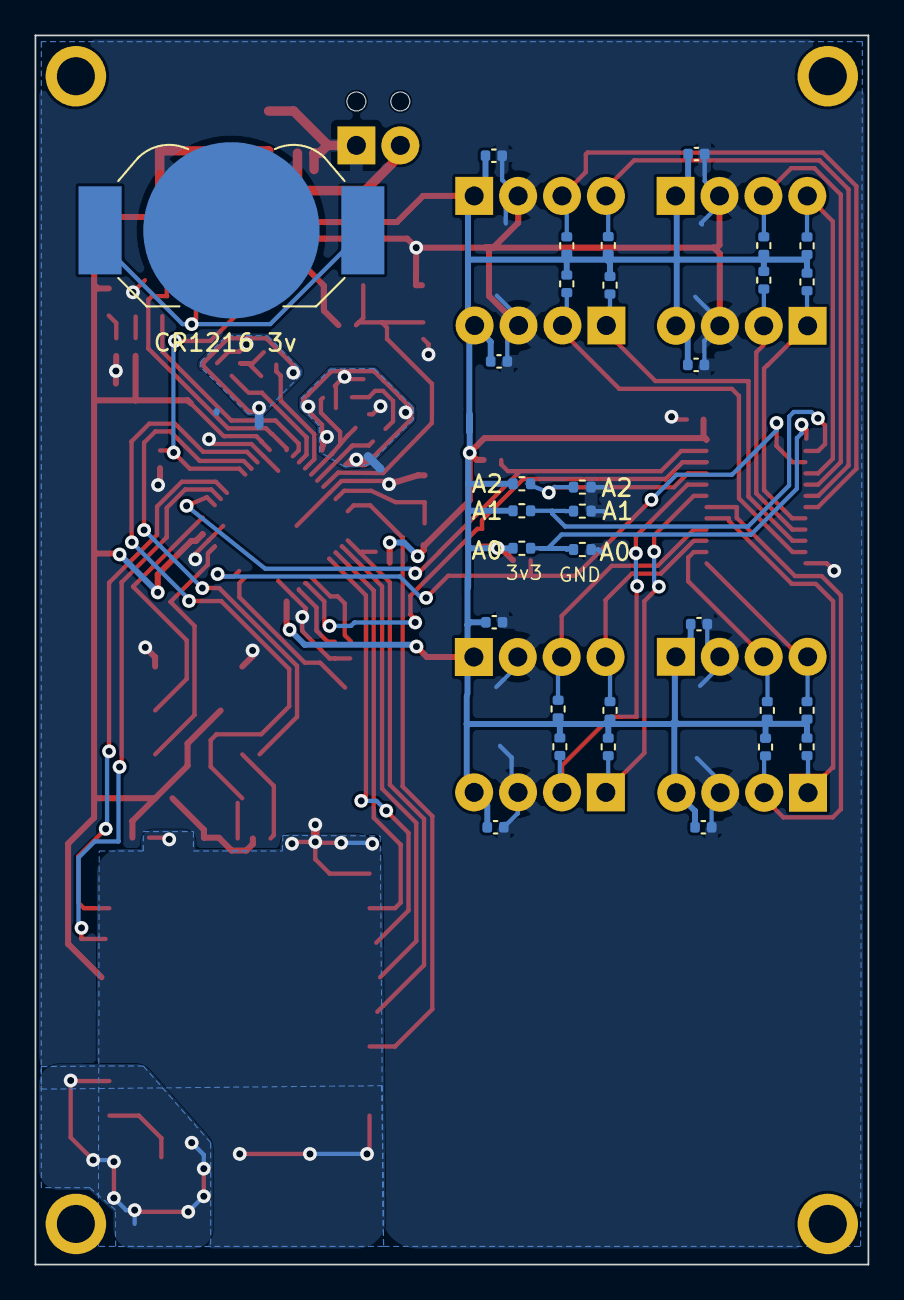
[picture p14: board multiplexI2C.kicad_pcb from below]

Board: 2 copper layers, 48.2 x 71.1 mm, 96 parts (33 on the bottom side), 58 nets.

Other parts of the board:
G1: LOGO; SensorProject_QR
G2: LOGO; SensorProject_IDblock

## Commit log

2024-07-28 add first draft, schematic. PCB still old from copied template.
2024-07-30 schematic first draft done, starting to populate pcb.
    [connector.kicad_sch, multiplexI2C.kicad_pcb, multiplexI2C.kicad_sch]
2024-08-04 ERC and DRC warnings but not erros. Needs some layout adjustments.
    [connector.kicad_sch, multiplexI2C.kicad_pcb, multiplexI2C.kicad_sch]
2024-08-06 no ELC or DRC errors. Still cleaning up warnings. Switched to SW_DIP for PCA9548 address.
    [connector.kicad_sch, multiplexI2C.kicad_pcb, multiplexI2C.kicad_sch]
2024-08-07 roughly complete, no errors or warnings.
    [connector.kicad_sch, multiplexI2C.kicad_pcb, multiplexI2C.kicad_sch]
2024-08-07 adding Graphics to README.
    [multiplexI2C.kicad_pcb]
2024-08-07 trying to view 3D from README.
    [multiplexI2C.stl]
2024-08-16 put masks on takeoffPads and other ongoing cleanup.
    [connector.kicad_sch, multiplexI2C.kicad_pcb, multiplexI2C.kicad_sch]
2024-08-16 playing with 3D graphics file in README.
    [multiplexI2C.step]
2024-08-19 clean up symbol fields
    [connector.kicad_sch, multiplexI2C.kicad_sch]
2024-08-20 passing checks with TCA9548A in pass. Ongoingg cleanup.
    [multiplexI2C.kicad_pcb, multiplexI2C.kicad_sch]
2024-08-20 converted to TCA9548A, cleaned up and regenerated graphics. No ERC or DRC errors.
    [multiplexI2C.kicad_pcb, multiplexI2C.step]
2024-08-20 added TCA footprint to ProjectLib. Minor cleanup and fiddling with README graphics.
    [multiplexI2C.kicad_pcb, multiplexI2C.kicad_sch]
2024-08-21 added header for ssd1306.
    [multiplexI2C.kicad_pcb, multiplexI2C.kicad_sch]
2024-08-21 ssd1306 header cleanup.
    [multiplexI2C.kicad_pcb]
2024-08-24 replaced address switch with R0 changeable by solder.
    [multiplexI2C.kicad_pcb, multiplexI2C.kicad_sch]
2024-08-24 replaced address switch with R0 changeable by solder. Cleanup.
    [multiplexI2C.kicad_pcb]
2024-08-25 squeezed connectors closer together to make room for sx127x module.
    [multiplexI2C.kicad_pcb]
2024-08-29 added RFM95W pad for sx127x, unpopulated.
    [multiplexI2C.kicad_pcb, multiplexI2C.kicad_sch]
2024-08-29 added fill zone behind radio and other cleanup.
    [multiplexI2C.kicad_pcb]
2024-08-30 adding radio-sx127x files, revised graphics and notes.
    [multiplexI2C.step, radio-sx127x.kicad_sch]
2024-09-04 e220 schematic needs work, and proper DIO connections. Switching back to radio-sx127.
    [E220-900M22S.kicad_sch, multiplexI2C.kicad_sch]
2024-09-04 renamed radio-sx127x.kicad_sch to RFM95W.kicad_sch
    [E220-900M22S.kicad_sch, RFM95W.kicad_sch, multiplexI2C.kicad_sch]
2024-09-07 some cleanup. About to split two lra module branches.
    [E220-900M22S.kicad_sch, RFM95W.kicad_sch, multiplexI2C.kicad_pcb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]
2024-09-07 DRC ot errors. 3D not showing U2.
    [multiplexI2C.kicad_pcb, multiplexI2C.kicad_sch]
2024-09-07 added antenna connector.
    [RFM95W.kicad_sch, multiplexI2C.kicad_pcb, multiplexI2C.kicad_sch]
2024-09-08 added antenna. No 3d yet.
    [RFM95W.kicad_sch, multiplexI2C.kicad_pcb, multiplexI2C.kicad_sch]
2024-09-08 Working on 3dmodels. ssd header messed up.
    [connector.kicad_sch, multiplexI2C.kicad_pcb, multiplexI2C.kicad_sch]
2024-09-08 ssd header fixed. Ongoing work on 3d models.
    [multiplexI2C.kicad_pcb, multiplexI2C.kicad_sch]
2024-09-08 3D working but antenna is not yet good. ERC and DRC no errors. BOM needs adjustments.
    [multiplexI2C.kicad_pcb, multiplexI2C.kicad_sch]
2024-09-10 cleaning up details forbetter BOM generator.
    [connector.kicad_sch, multiplexI2C.kicad_pcb, multiplexI2C.kicad_sch]
2024-09-15 as ordered 2024-09 with minor changes for part availability.
    [multiplexI2C.kicad_pcb, multiplexI2C.kicad_sch]
2025-01-06 added 10k pullup on NSS.
    [RFM95W.kicad_sch, multiplexI2C.kicad_pcb]
2025-09-07 minor doc cleanup.
    [multiplexI2C.kicad_sch]
2025-09-07 ongoing conversion to put f411 on board rather than pinsocket.
    [HSE.kicad_sch, LSE.kicad_sch, RFM95W.kicad_sch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]
2025-09-07 ongoing add of MCU, etc.
    [HSE.kicad_sch, LSE.kicad_sch, RFM95W.kicad_sch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]
2025-09-08 symbols an footprints added for f411 change. ERC passes.
    [HSE.kicad_sch, LSE.kicad_sch, RFM95W.kicad_sch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]
2025-11-10 adding MCU, ongoing.
    [HSE.kicad_sch, LSE.kicad_sch, RFM95W.kicad_sch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]
2025-11-22 th8-f411 with castellated MCU-LoRa. DRC clean, ERC with some warnings.
    [f411.kicad_sch, multiplexI2C.kicad_pcb, multiplexI2C.kicad_sch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]
2025-11-25 four sensor connectors flipped to the way they should be installed.
    [connector_flipped.kicad_sch, f411.kicad_sch, multiplexI2C.kicad_pcb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]
2025-11-25 changed single 10k pull-up to 4.7k like others. Renumbered components to fill numbering gaps.
    [connector.kicad_sch, connector_flipped.kicad_sch, f411.kicad_sch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]
2025-11-25 cleaned up fab layer annotation.
    [connector.kicad_sch, connector_flipped.kicad_sch, f411.kicad_sch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]
2025-11-27 3d showing well with MCU-LoRa step model. Clean up of silkscreen and fab layers. Small movement of some components so silkscreen label placement is better.
    [f411.kicad_sch, multiplexI2C.kicad_pcb, multiplexI2C.step]
2025-11-29 more cleanup.
    [E220-900M22S.kicad_sch]
2025-12-01 schematic good. Footprint placement ongoing.
    [HSE.kicad_sch, LSE.kicad_sch, RFM95W.kicad_sch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]
2025-12-03 ERC and DRC good. Needs fab layer cleanup.
    [RFM95W.kicad_sch, f411.kicad_sch, multiplexI2C.kicad_pcb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]
2025-12-03 adjusted copper zones and mounting holes for better setback from edge. Fab layers cleanup and some documentation cleanup.
    [multiplexI2C.kicad_pcb, multiplexI2C.step, multiplexI2C.stl]
2025-12-05 ongoing cleanup for submit.
    [HSE.kicad_sch, LSE.kicad_sch, RFM95W.kicad_sch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]
2026-04-02 th8-F411 2025-12 plus some cleanup post manufacturing.
    [HSE.kicad_sch, LSE.kicad_sch, RFM95W.kicad_sch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]
2026-04-09 superficial adjustments for warnings found by kicaad 10.
    [HSE.kicad_sch, LSE.kicad_sch, RFM95W.kicad_sch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]
